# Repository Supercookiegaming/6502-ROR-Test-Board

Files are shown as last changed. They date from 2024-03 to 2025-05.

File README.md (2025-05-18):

# 6502-ROR-Test-Board

The 6502 ROR Test Board is a simple computer that tests if the ROR insruction is present on the 6502. I/O space is from 0x0000 to 0x7FFF. Rom space starts at 0x8000 and ends at 0xFFFF. The LED is tied to bit 7 and is set when the CPU R/W is low (writing). The data is then latched into the D-Latch and will be held until updated. The Yes ROR LED is turned on when the cpu writes to any memeory in the I/O space and bit 7 is high, all other bits do nothing. The No ROR LED is turned on whent he cpu writes to any memeory in the I/O space and bit 7 is low.
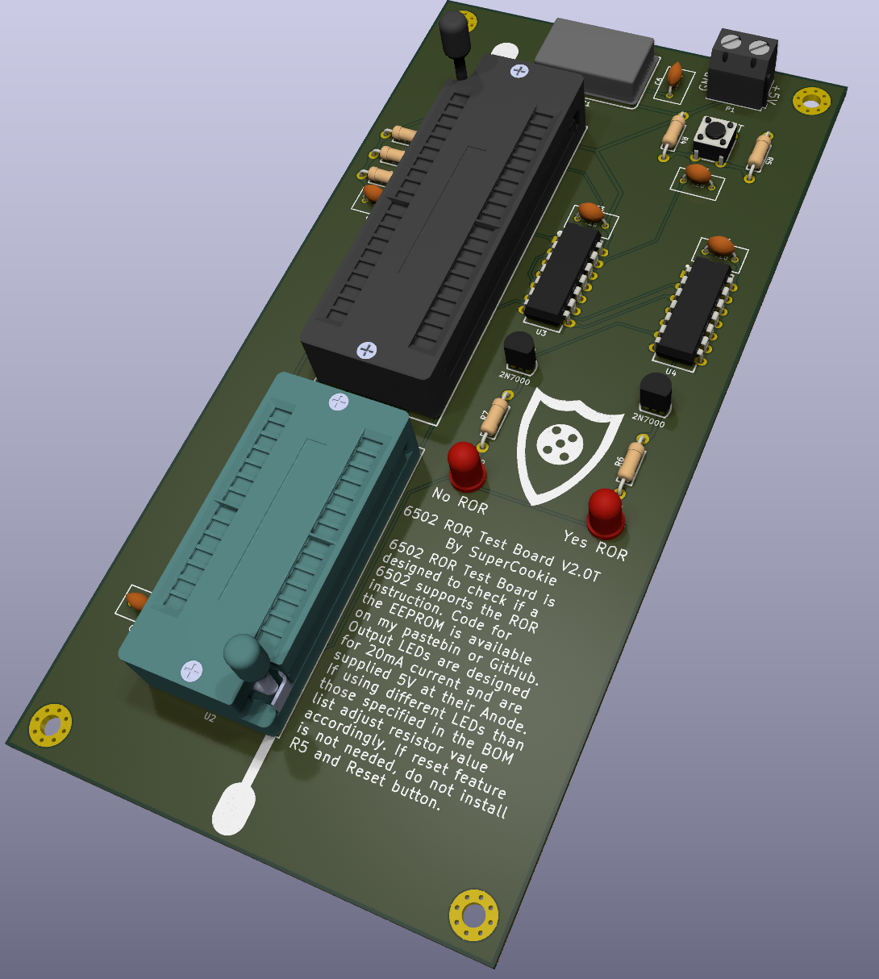
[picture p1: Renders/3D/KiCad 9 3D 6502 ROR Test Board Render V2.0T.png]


[logo]: https://github.com/Supercookiegaming/6502-ROR-Test-Board/blob/350ec1a620519f19180ad02e0bde4138ba3418b3/Renders/3D/KiCad%209%203D%206502%20ROR%20Test%20Board%20Render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
I used https://www.masswerk.at/6502/assembler.html to assemble the rom code and create a BIN file. When using https://www.masswerk.at/6502/# to emulate the board, use the code marked as "Emulator". When the ROR bug is enabled 0x0010 will be 00 and when it is disabled 0x0010 will be 80.

When Building your own board its best to use sockets.

V2.0S uses mostly SMD parts (mostly 0603). V2.0T only has through hole components. 

EasyEDA and KiCad 9 files are now available for both boards. 

The design is free for personally use only.

V2.0S and V2.0T both now support zif sockets for the 6502 and AT28C256, the imporved reset circuit design, ground M3 mounting points, and better silkscreen instructions and pinouts.

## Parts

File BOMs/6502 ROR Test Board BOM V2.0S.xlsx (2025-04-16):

Part | QTY | Link
2.2k Resistor | 4 | https://www.digikey.com/en/products/detail/walsin-technology-corporation/WR06X2201FTL/13238691
150 Resistor | 2 | https://www.digikey.com/en/products/detail/walsin-technology-corporation/WR06X151-JTL/13238810 | * It is strongly recommended to have zif sockets for the 6502 and AT28C256
0.1uF Capacitor | 6 | https://www.digikey.com/en/products/detail/meritek/MA1206XR104K101/20116994
2N7002 | 2 | https://www.mouser.com/ProductDetail/Nexperia/2N7002NXBKR?qs=%252B6g0mu59x7J2ddJstTJGkQ%3D%3D
SN74HCS74DR | 1 | https://www.digikey.com/en/products/detail/texas-instruments/SN74HCS74DR/12352265
SN74HCT14DR | 1 | https://www.digikey.com/en/products/detail/texas-instruments/SN74HCT14DR/562918
1Mhz Clock Generator | 1 | https://www.digikey.com/en/products/detail/analog-devices-inc-maxim-integrated/MAX7375AXR105-T/1520107
AT28C256 | 1 | https://www.mouser.com/ProductDetail/Microchip-Technology/AT28C256-15PU?qs=MAR%2F2X5XOp7eAU2%2FlNw9oA%3D%3D
6502 | 1
0603 LED | 2 | https://www.digikey.com/en/products/detail/harvatek-corporation/B19Y1USD-20C000113U1930/16602930
2 pin screw terminal | 1 | https://www.mouser.com/ProductDetail/845-30.702
Reset (optional)
smd button | 1 | https://www.lcsc.com/product-detail/Tactile-Switches_Korean-Hroparts-Elec-K2-1107ST-A4DW-06_C118141.html
150 Resistor | 1 | https://www.digikey.com/en/products/detail/walsin-technology-corporation/WR06X151-JTL/13238810
Normal Dip Sockets (optional*)
40 pin dip socket | 1 | https://www.jameco.com/z/40MTLP-Jameco-ValuePro-40-Pin-Machine-Tooled-Low-Profile-IC-Socket-0-6-Inch-Wide_41136.html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
28 pin dip socket | 1 | https://www.digikey.com/en/products/detail/mill-max-manufacturing-corp./110-44-628-41-001000/947065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
ZIF Sockets (optional*)
40 pin ZIF socket | 1 | https://www.adafruit.com/product/383#description
28 pin ZIF socket | 1 | https://www.ebay.com/itm/264998977768

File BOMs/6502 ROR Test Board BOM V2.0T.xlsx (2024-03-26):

Part | QTY | Link
2.2k Resistor | 4 | https://www.digikey.com/en/products/detail/stackpole-electronics-inc/CF14JT2K20/1830358?gad_source=1
150 Resistor | 2 | https://www.digikey.com/en/products/detail/stackpole-electronics-inc/CF18JT150R/1741590 | * It is strongly recommended to have zif sockets for the 6502 and AT28C256
0.1uF Capacitor | 6 | https://www.mouser.com/ProductDetail/Vishay-BC-Components/K104K10X7RF53H5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
2N7000 | 2 | https://www.digikey.com/en/products/detail/onsemi/2N7000/244278
SN74LS74AN | 1 | https://www.mouser.com/ProductDetail/Texas-Instruments/SN74LS74AN?qs=b0gIXGU74fP41yYZQO4%252BKQ%3D%3D
SN74HCT14N | 1 | https://www.mouser.com/ProductDetail/Texas-Instruments/SN74HCT14N?qs=d9gICRQKuCds9VLhv7zR%2Fg%3D%3D
1Mhz Clock Generator | 1 | https://www.mouser.com/ProductDetail/CTS-Electronic-Components/MXO45-3C-1M0000?qs=hbgUSdfWRJUFs0kP0zCadA%3D%3D
AT28C256 | 1 | https://www.mouser.com/ProductDetail/Microchip-Technology/AT28C256-15PU?qs=MAR%2F2X5XOp7eAU2%2FlNw9oA%3D%3D
6502 | 1
333-2SURD/S530-A3 LED | 2 | https://www.lcsc.com/product-detail/Light-Emitting-Diodes-LED_Everlight-Elec-333-2SURD-S530-A3_C87271.html
2 pin screw terminal | 1 | https://www.mouser.com/ProductDetail/845-30.702
Reset (optional)
6x6mm button | 1 | https://www.digikey.com/en/products/detail/cui-devices/TS02-66-60-BK-100-LCR-D/15634327?gad_source=1
150 Resistor | 1 | https://www.digikey.com/en/products/detail/stackpole-electronics-inc/CF18JT150R/1741590
Normal Dip Sockets (optional*)
40 pin dip socket | 1 | https://www.jameco.com/z/40MTLP-Jameco-ValuePro-40-Pin-Machine-Tooled-Low-Profile-IC-Socket-0-6-Inch-Wide_41136.html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
28 pin dip socket | 1 | https://www.digikey.com/en/products/detail/mill-max-manufacturing-corp./110-44-628-41-001000/947065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
14 pin dip socket | 2 | https://www.digikey.com/en/products/detail/on-shore-technology-inc./SA143040/3313523?gad_source=1
ZIF Sockets (optional*)
40 pin ZIF socket | 1 | https://www.adafruit.com/product/383#description
28 pin ZIF socket | 1 | https://www.ebay.com/itm/264998977768

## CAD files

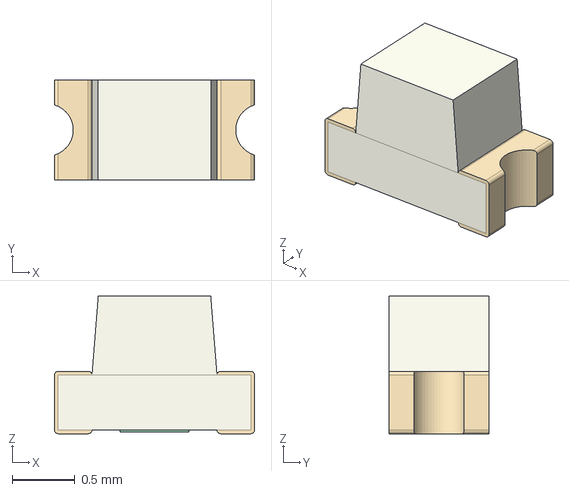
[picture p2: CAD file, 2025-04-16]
EDA Files/KiCad 9 6502 ROR Test Board V2.0S/LED_0603_1608Metric_Castellated.step
1.60 x 0.8 x 1.10 mm

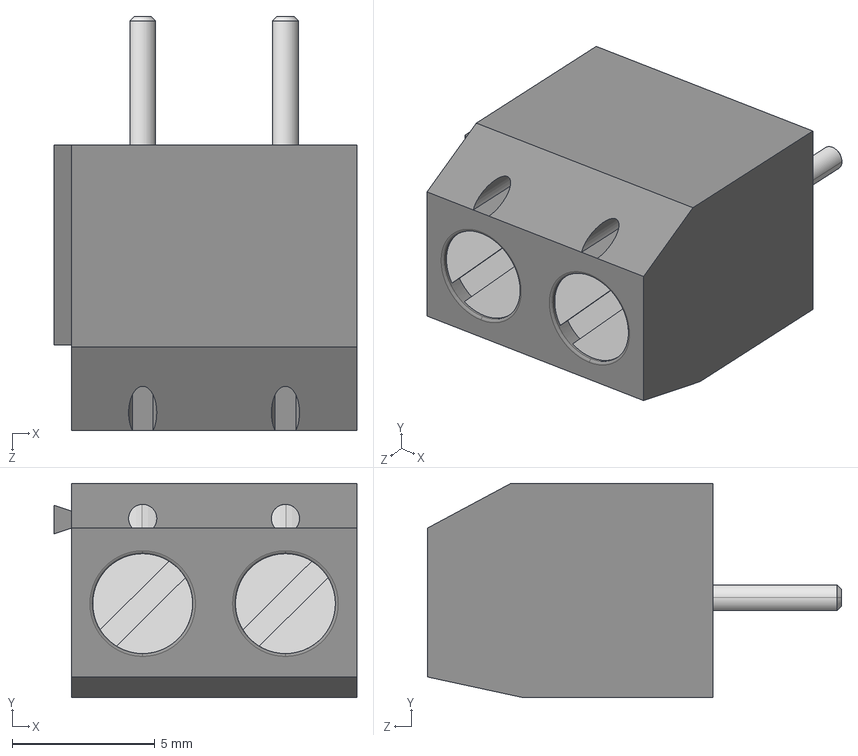
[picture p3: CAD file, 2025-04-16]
EDA Files/KiCad 9 6502 ROR Test Board V2.0T/30.702.stp
10.6 x 7.50 x 14.5 mm

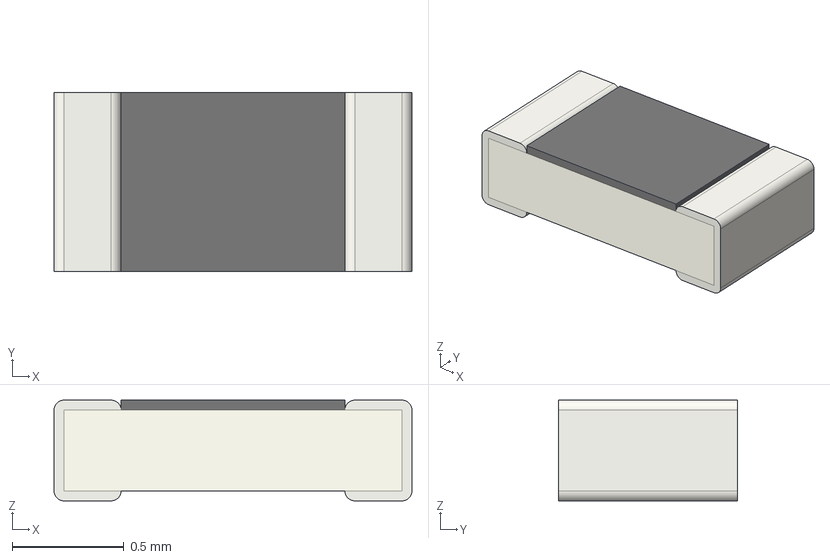
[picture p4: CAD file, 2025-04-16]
EDA Files/KiCad 9 6502 ROR Test Board V2.0S/R_0603_1608Metric.step
1.60 x 0.8 x 0.45 mm

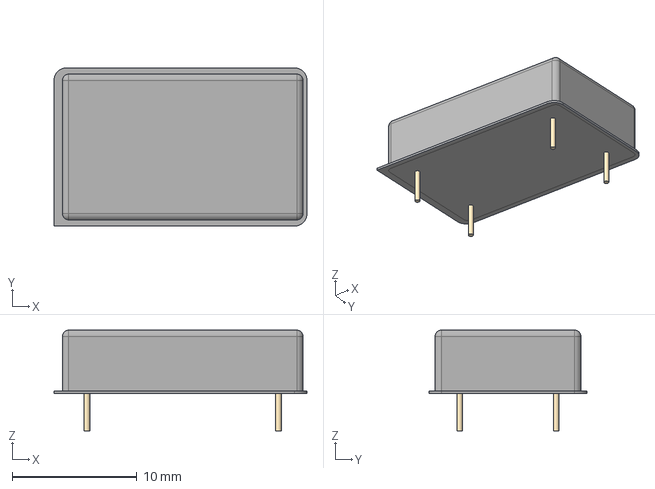
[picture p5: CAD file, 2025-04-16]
EDA Files/KiCad 9 6502 ROR Test Board V2.0T/Oscillator_DIP-14.step
20.3 x 12.7 x 8.08 mm

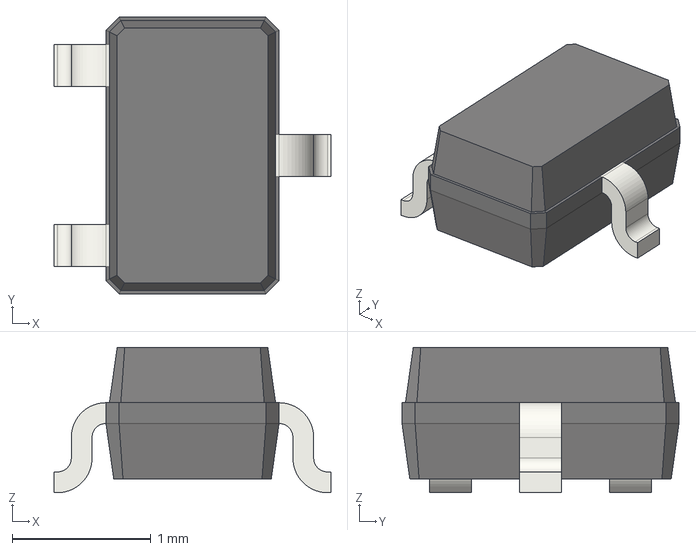
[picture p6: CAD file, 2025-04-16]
EDA Files/KiCad 9 6502 ROR Test Board V2.0S/SOT-323_SC-70.step
2.00 x 2.00 x 1.05 mm

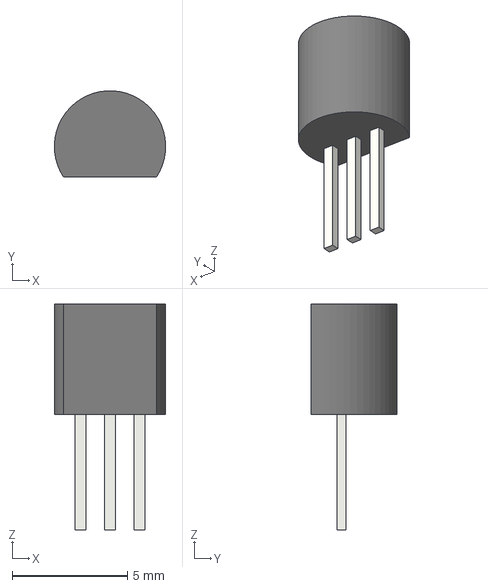
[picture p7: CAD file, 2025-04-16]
EDA Files/KiCad 9 6502 ROR Test Board V2.0T/TO-92_Inline.step
4.83 x 3.74 x 9.80 mm

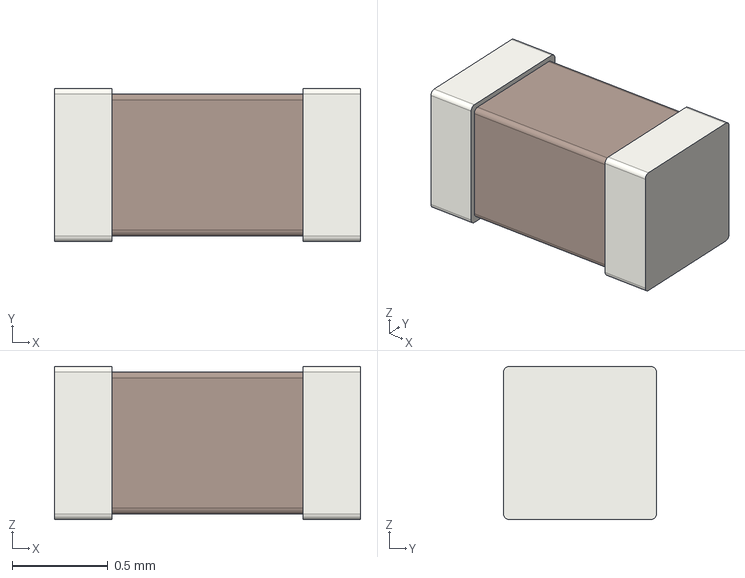
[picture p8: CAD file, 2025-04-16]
EDA Files/KiCad 9 6502 ROR Test Board V2.0S/C_0603_1608Metric.step
1.60 x 0.8 x 0.8 mm

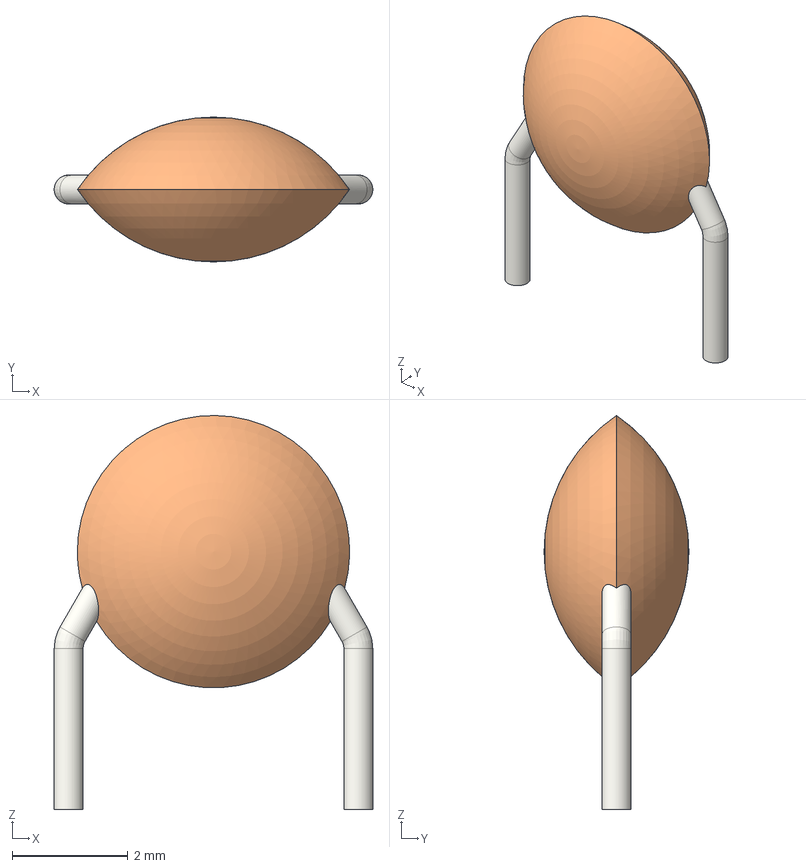
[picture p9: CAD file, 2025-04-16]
EDA Files/KiCad 9 6502 ROR Test Board V2.0T/C_Disc_D4.7mm_W2.5mm_P5.00mm.step
5.50 x 2.50 x 6.80 mm

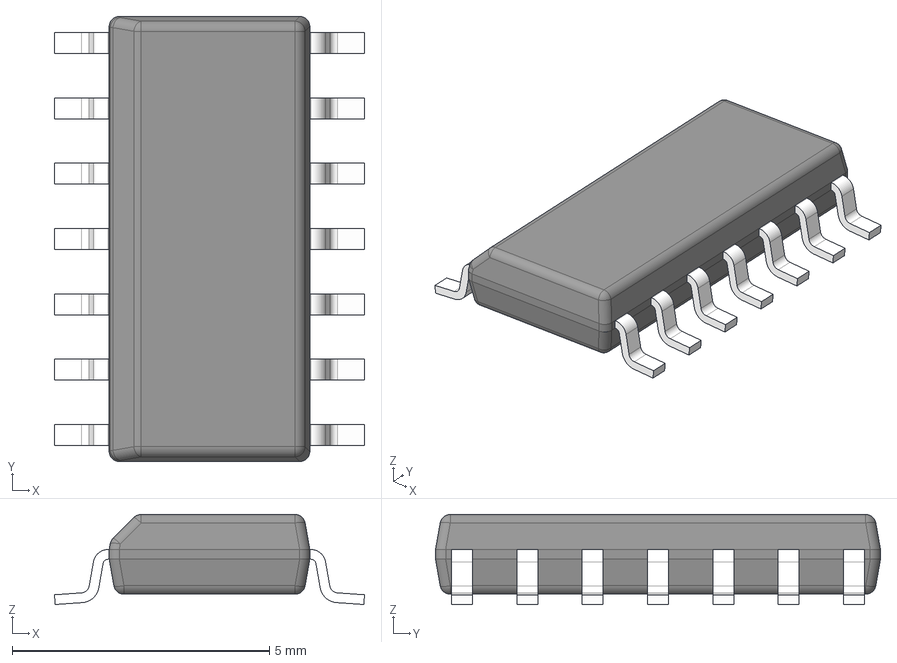
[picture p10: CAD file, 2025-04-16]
EDA Files/KiCad 9 6502 ROR Test Board V2.0S/SN74HCT14DR.stp
6.03 x 8.65 x 1.75 mm
BODY-SO
LEAD-SO x 14
PIN1-ID

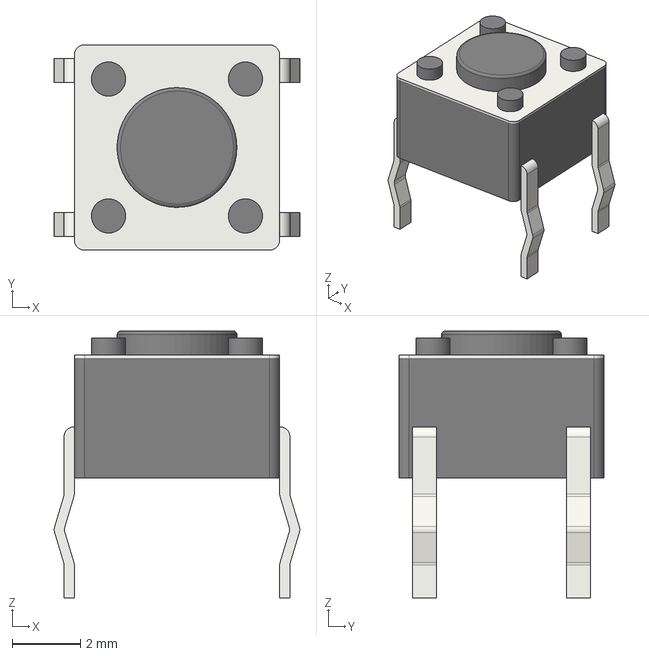
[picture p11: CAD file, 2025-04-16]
EDA Files/KiCad 9 6502 ROR Test Board V2.0T/SW_PUSH_6mm.step
7.17 x 6.00 x 7.80 mm

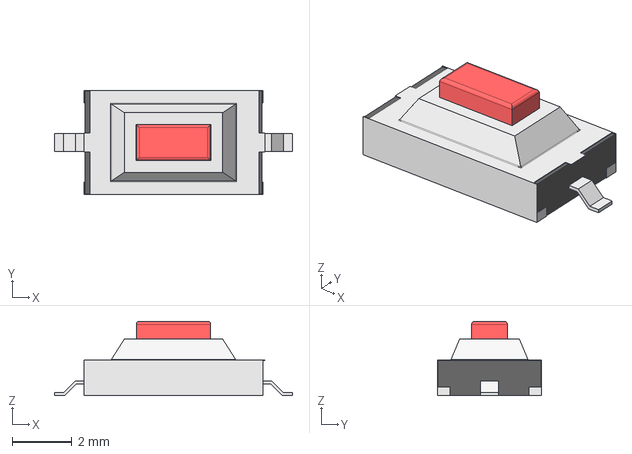
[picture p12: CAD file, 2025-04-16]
EDA Files/KiCad 9 6502 ROR Test Board V2.0S/SW_SPST_CK_RS282G05A3.step
8.00 x 3.50 x 2.50 mm

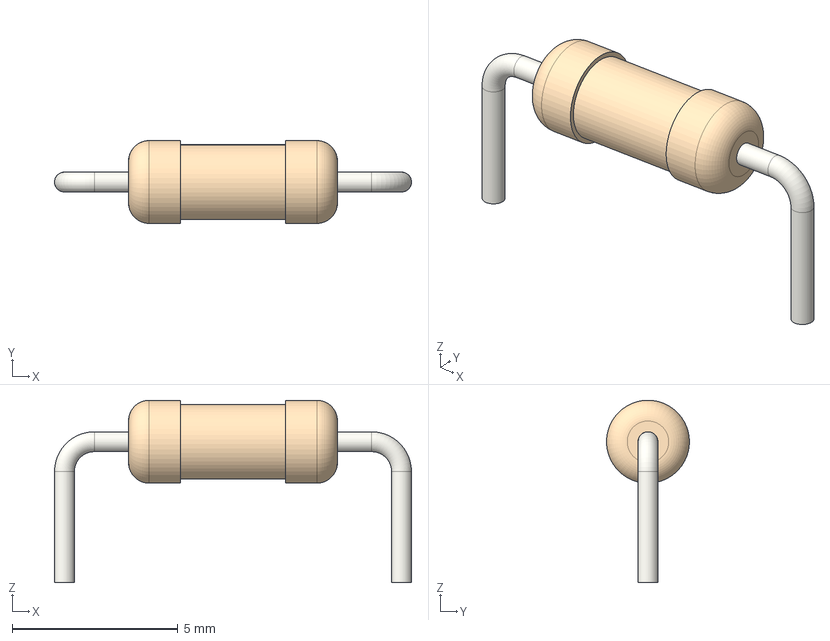
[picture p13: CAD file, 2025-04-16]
EDA Files/KiCad 9 6502 ROR Test Board V2.0T/R_Axial_DIN0207_L6.3mm_D2.5mm_P10.16mm_Horizontal.step
10.8 x 2.50 x 5.50 mm

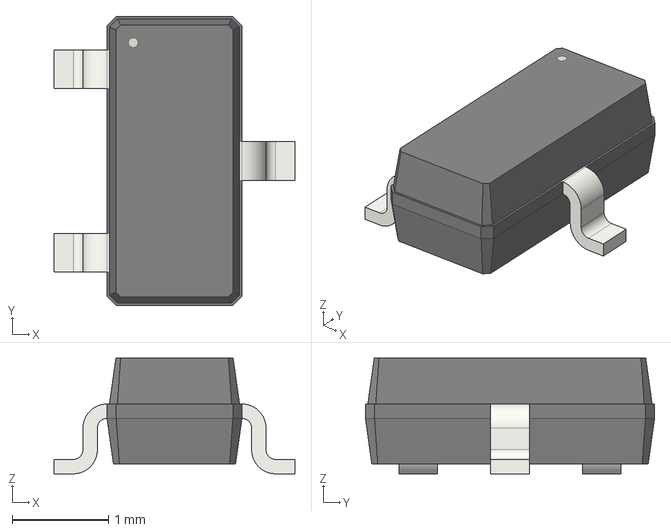
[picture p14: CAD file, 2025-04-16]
EDA Files/KiCad 9 6502 ROR Test Board V2.0S/SOT-23-3.step
2.50 x 3.00 x 1.20 mm

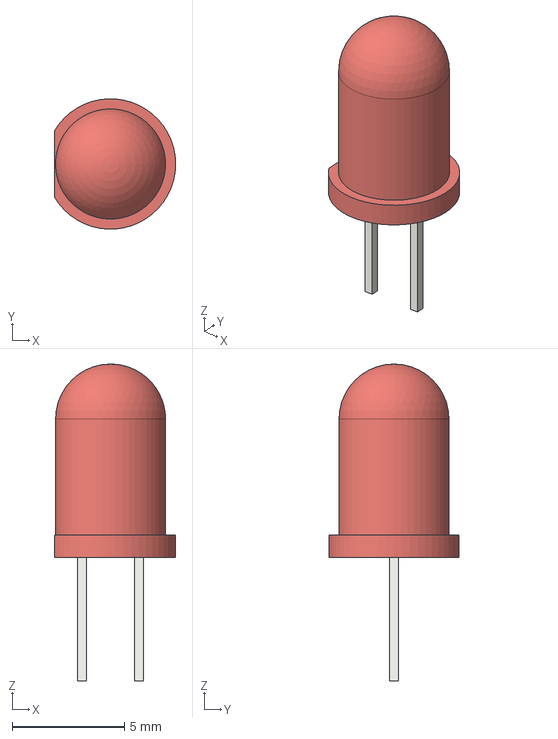
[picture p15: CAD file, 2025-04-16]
EDA Files/KiCad 9 6502 ROR Test Board V2.0T/LED_D5.0mm.step
5.40 x 5.79 x 14.1 mm

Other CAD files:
EDA Files/KiCad 9 6502 ROR Test Board V2.0T/DIP-14_W7.62mm.step
EDA Files/KiCad 9 6502 ROR Test Board V2.0S/228-1277-00-0602J.STEP
EDA Files/KiCad 9 6502 ROR Test Board V2.0T/240-1280-00-0602J.STEP
EDA Files/KiCad 9 6502 ROR Test Board V2.0S/240-1280-00-0602J.STEP
EDA Files/KiCad 9 6502 ROR Test Board V2.0T/228-1277-00-0602J.STEP

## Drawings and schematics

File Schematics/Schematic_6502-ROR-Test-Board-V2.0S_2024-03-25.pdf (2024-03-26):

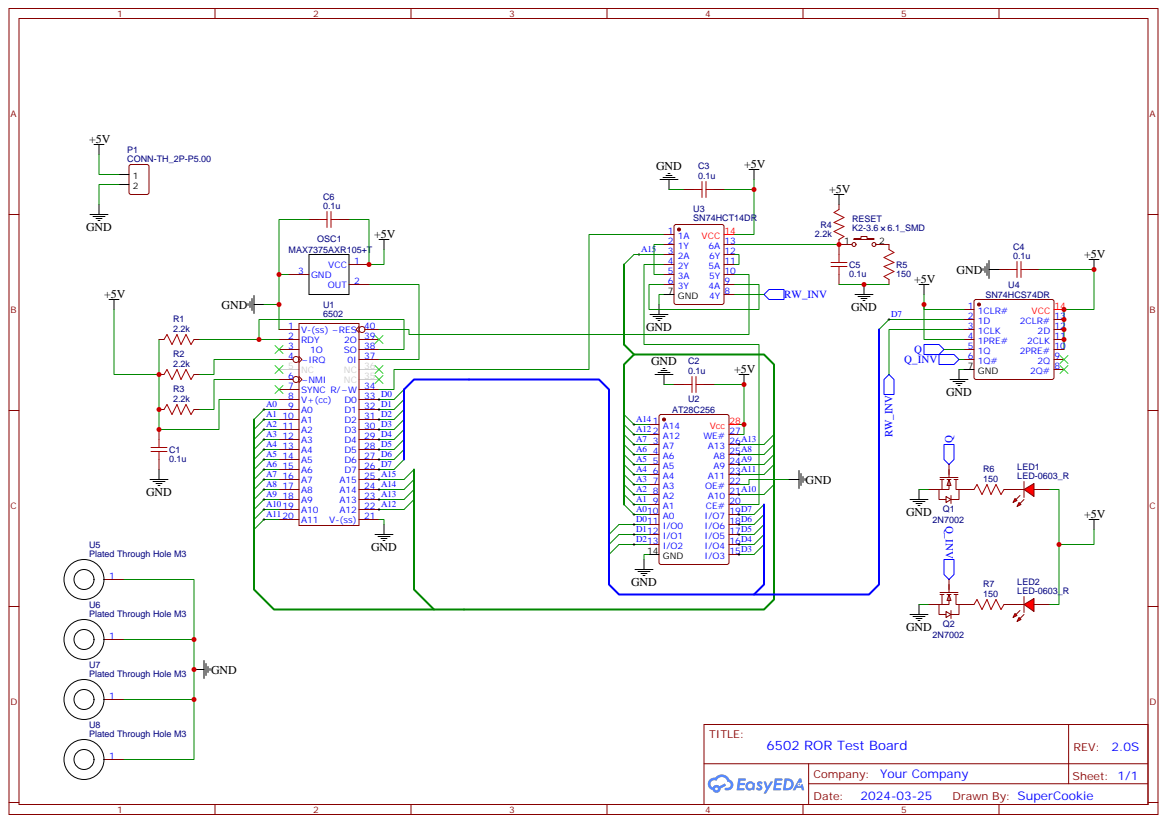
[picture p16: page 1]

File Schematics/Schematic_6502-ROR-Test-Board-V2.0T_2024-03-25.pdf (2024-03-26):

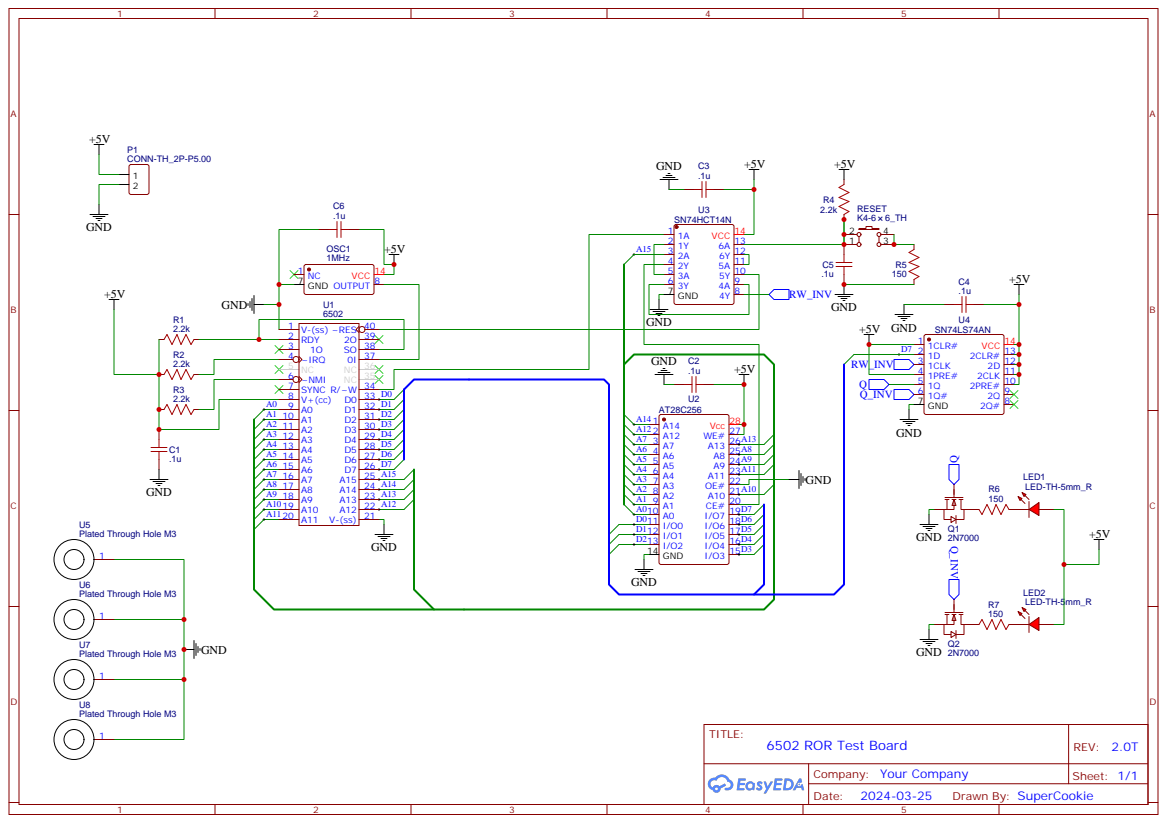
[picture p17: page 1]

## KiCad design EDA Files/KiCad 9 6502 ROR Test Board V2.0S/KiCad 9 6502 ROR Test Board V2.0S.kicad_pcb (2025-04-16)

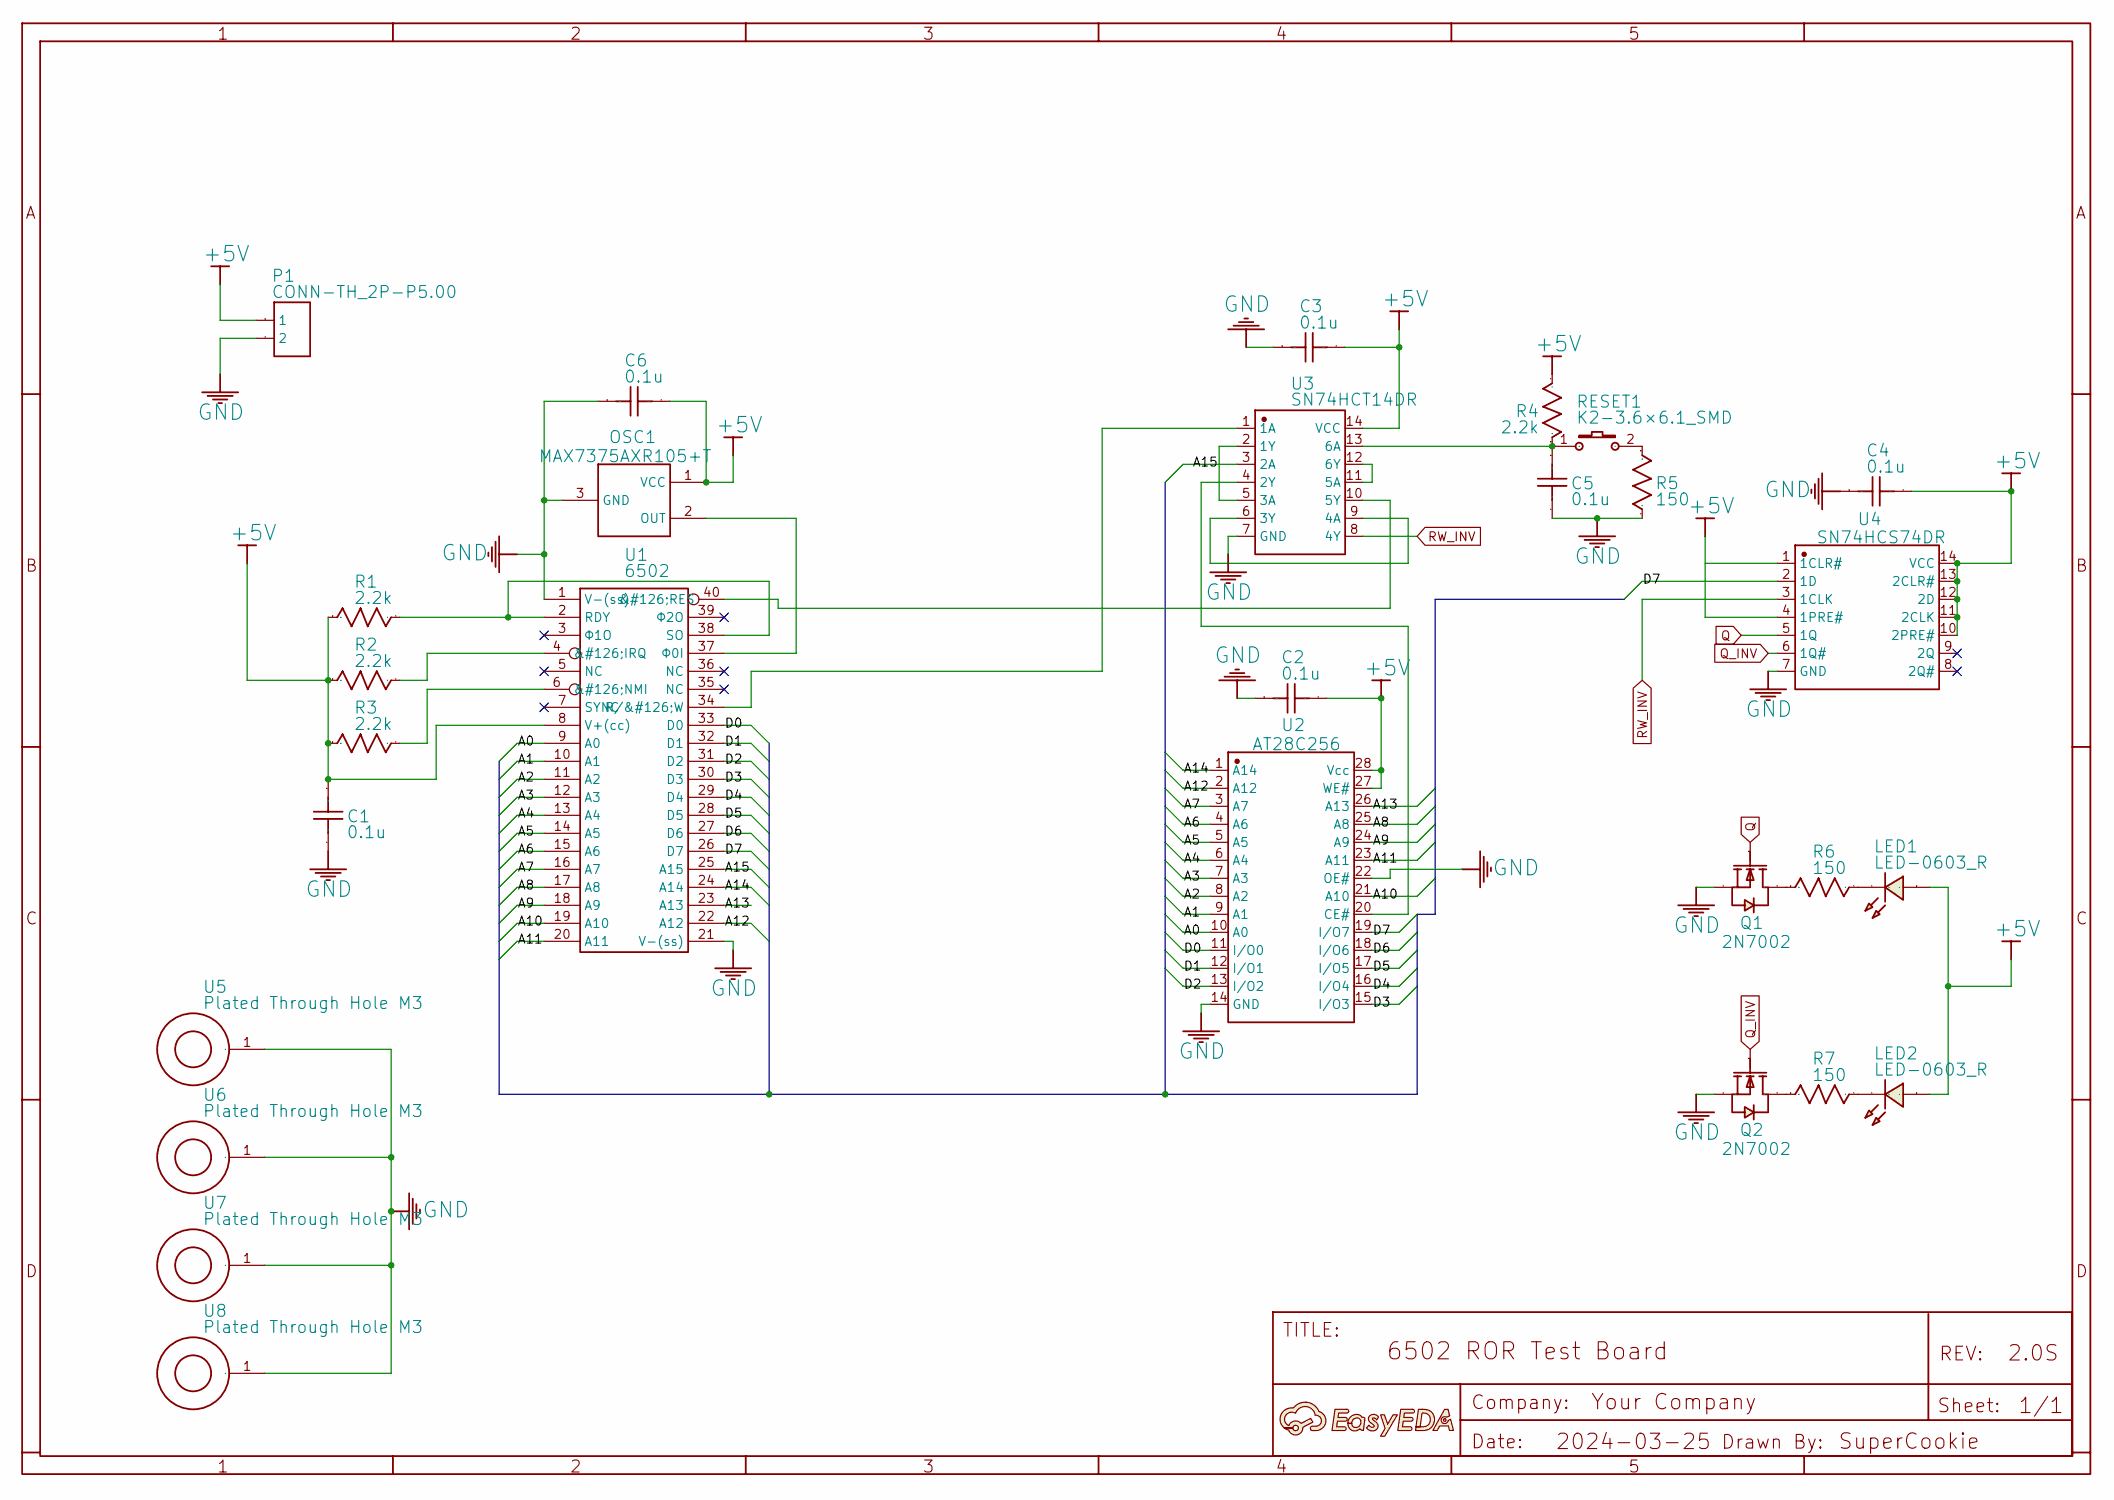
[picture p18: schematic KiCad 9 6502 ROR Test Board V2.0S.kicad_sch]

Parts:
A1: A; Manufacturer Part ?
C1, C2, C3, C4, C5, C6: 0.1u
LED1, LED2: LED-0603_R; Manufacturer Part 19-217/R6C-AL1M2VY/3T
OSC1: MAX7375AXR105+T; Manufacturer Part MAX7375AXR105+T
P1: CONN-TH_2P-P5.00
Q1, Q2: 2N7002; Manufacturer Part 2N7002,215
R1, R2, R3, R4: 2.2k
R5, R6, R7: 150
RESET1: K2-3.6×6.1_SMD; Manufacturer Part K2-1107ST-A4SW-06
U1: 6502
U2: AT28C256; Manufacturer Part AT28C256-15PU
U3: SN74HCT14DR; Manufacturer Part SN74HCT14DR
U4: SN74HCS74DR; Manufacturer Part SN74HCS74DR
U5, U6, U7, U8: Plated Through Hole M3

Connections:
+5V: C1.1, C2.2, C3.2, C4.2, C6.2, LED1.1, LED2.1, OSC1.1 (VCC), P1.1, R1.1, R2.1, R3.1, R4.2, U1.8 (V+(cc)), U2.27 (WE#), U2.28 (Vcc), U3.14 (VCC), U4.4 (1PRE#), U4.10 (2PRE#), U4.11 (2CLK), U4.12 (2D), U4.13 (2CLR#), U4.14 (VCC)
/A0: U1.9 (A0), U2.10 (A0)
/A1: U1.10 (A1), U2.9 (A1)
/A2: U1.11 (A2), U2.8 (A2)
/A3: U1.12 (A3), U2.7 (A3)
/A4: U1.13 (A4), U2.6 (A4)
/A5: U1.14 (A5), U2.5 (A5)
/A6: U1.15 (A6), U2.4 (A6)
/A7: U1.16 (A7), U2.3 (A7)
/A8: U1.17 (A8), U2.25 (A8)
/A9: U1.18 (A9), U2.24 (A9)
/A10: U1.19 (A10), U2.21 (A10)
/A11: U1.20 (A11), U2.23 (A11)
/A12: U1.22 (A12), U2.2 (A12)
/A13: U1.23 (A13), U2.26 (A13)
/A14: U1.24 (A14), U2.1 (A14)
/A15: U1.25 (A15), U3.3 (2A)
/D0: U1.33 (D0), U2.11 (I/O0)
/D1: U1.32 (D1), U2.12 (I/O1)
/D2: U1.31 (D2), U2.13 (I/O2)
/D3: U1.30 (D3), U2.15 (I/O3)
/D4: U1.29 (D4), U2.16 (I/O4)
/D5: U1.28 (D5), U2.17 (I/O5)
/D6: U1.27 (D6), U2.18 (I/O6)
/D7: U1.26 (D7), U2.19 (I/O7), U4.2 (1D)
GND: C1.2, C2.1, C3.1, C4.1, C5.2, C6.1, OSC1.3 (GND), P1.2, Q1.2 (S), Q2.2 (S), R5.2, U1.1 (V-(ss)), U1.21 (V-(ss)), U2.14 (GND), U2.22 (OE#), U3.7 (GND), U4.7 (GND), U5.1, U6.1, U7.1, U8.1
unnamed: LED1.2, R6.2
unnamed: LED2.2, R7.2
unnamed: OSC1.2 (OUT), U1.37 (Φ0I)
unnamed: Q1.3 (D), R6.1
unnamed: Q2.3 (D), R7.1
unnamed: R5.1, RESET1.2
unnamed: R2.2, U1.4 (&#126;IRQ)
unnamed: R3.2, U1.6 (&#126;NMI)
unnamed: U1.40 (&#126;RES), U3.10 (5Y)
unnamed: R1.2, U1.2 (RDY), U1.38 (SO)
unnamed: U1.34 (R/&#126;W), U3.1 (1A)
unnamed: U2.20 (CE#), U3.4 (2Y)
unnamed: U3.2 (1Y), U3.5 (3A)
unnamed: U3.6 (3Y), U3.9 (4A)
unnamed: U3.11 (5A), U3.12 (6Y)
Q: Q1.1 (G), U4.5 (1Q)
Q_INV: Q2.1 (G), U4.6 (1Q#)
R4_1: C5.1, R4.1, RESET1.1, U3.13 (6A); also elsewhere on the board
RW_INV: U3.8 (4Y), U4.3 (1CLK)

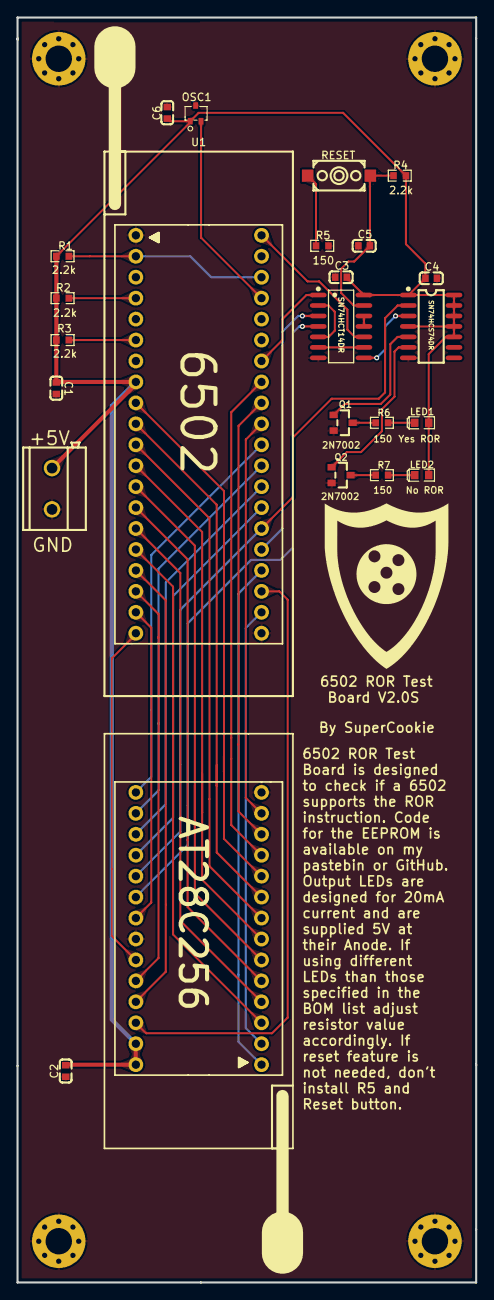
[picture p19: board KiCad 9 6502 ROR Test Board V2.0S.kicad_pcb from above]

Board: 2 copper layers, 55.6 x 153.4 mm, 28 parts (0 on the bottom side), 44 nets.

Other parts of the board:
RESET: K2-3.6×6.1_SMD; KEY-SMD_2P-L6.2-W3.6-LS8.0

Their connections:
R4_1: RESET.1; also elsewhere on the board

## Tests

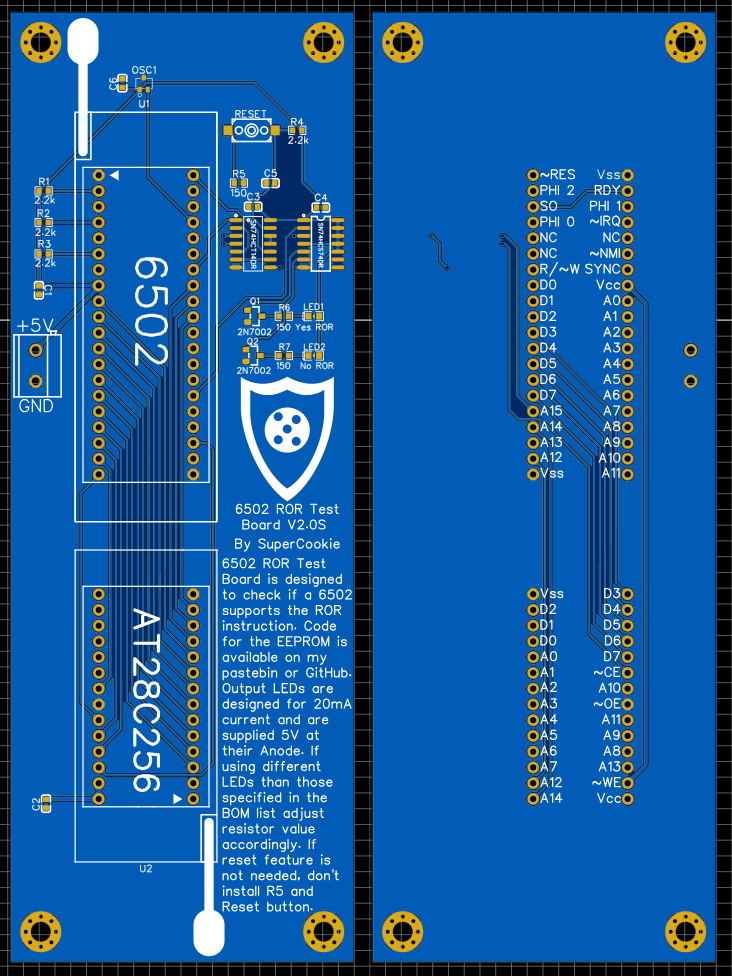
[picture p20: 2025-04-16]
Renders/2D/EasyEDA 6502 ROR Test Board Render V2.0S.png

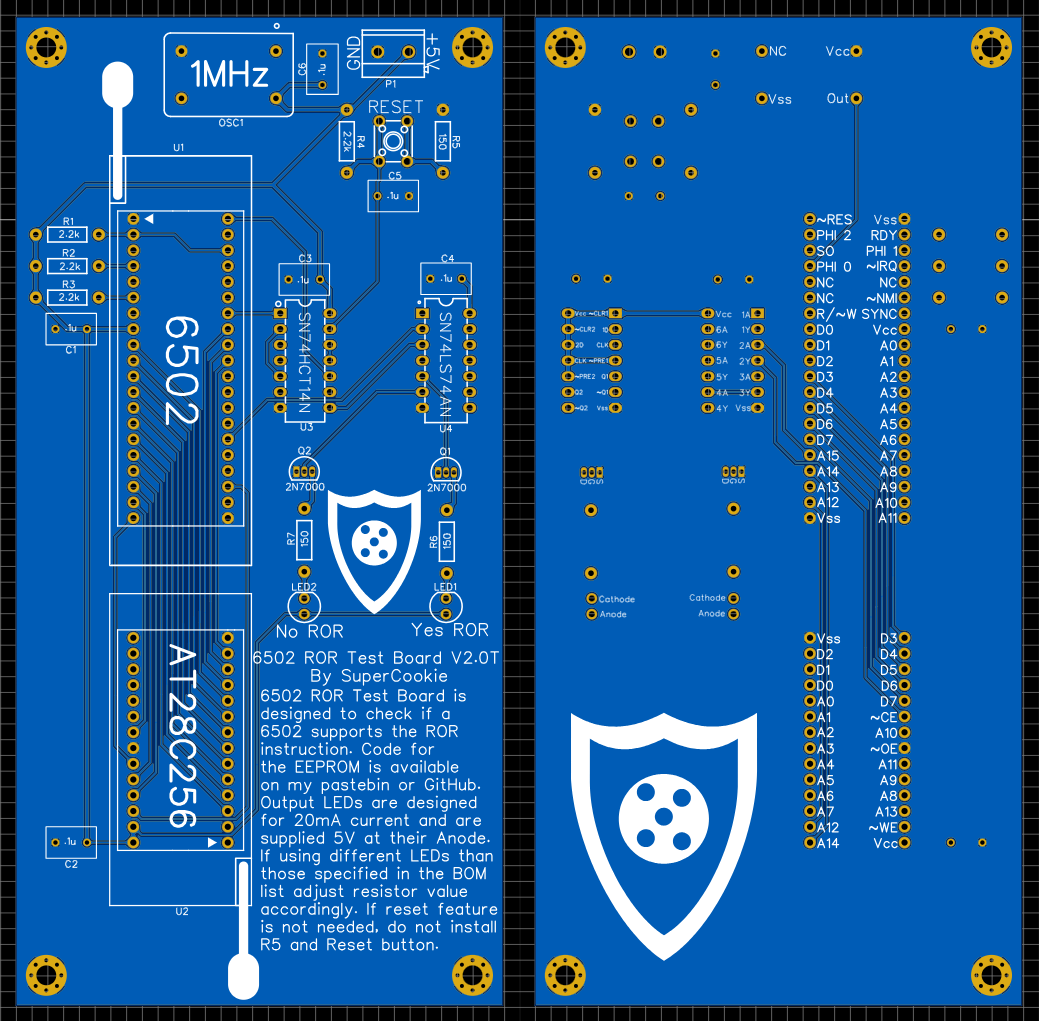
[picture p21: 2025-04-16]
Renders/2D/EasyEDA 6502 ROR Test Board Render V2.0T.png

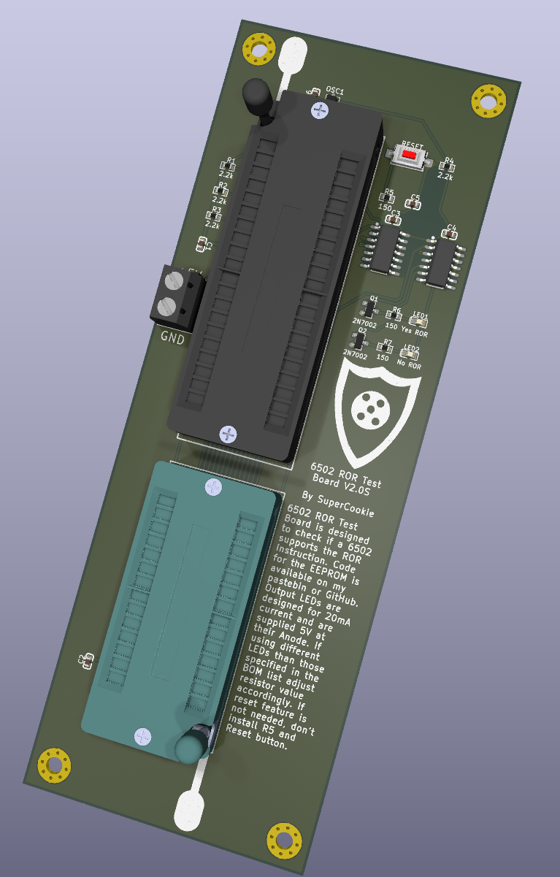
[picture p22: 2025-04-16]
Renders/3D/KiCad 9 3D 6502 ROR Test Board Render V2.0S.png

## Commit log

2023-12-22 Add files via upload
    V1.1 only uses through hole components. replaced the SN74LVC1G373DCKR with a SN74LS00N.
    [6502 ROR Test Board BOM V1.1.xlsx]
2023-12-22 Update 6502 ROR Test Board ROM Source Code.txt
2023-12-22 Rename 6502 ROR Test Board BOM.xlsx to 6502 ROR Test Board BOM V1.0.xlsx
    [6502 ROR Test Board BOM V1.0.xlsx]
2023-12-22 Rename 6502 ROR Test Board BOM V1.0.xlsx to 6502 ROR Test Board BOM V1.xlsx
    [6502 ROR Test Board BOM V1.xlsx]
2023-12-22 Add files via upload
    changed 2N7002 to correct 2N7000. added sockets for 555 and 74LS00
    [6502 ROR Test Board BOM V1.1.xlsx]
2023-12-24 Updated V1.1 to support optional ZIF sockets
    [6502 ROR Test Board BOM V1.1.xlsx]
2023-12-24 Cost reduced V1.1
    changed reset circuit to RC type. added push button reset option. reduced cost by remove 555 and changing 74LS00 to a hex shmitt trigger inverter (SN74HCT14N) and a D-Type Latch and Flip-Flop (SN74LS74AN). also reduced types of components needed to 1 type of capacitor and 2 types of resistor. Added better skillscreen instructions. Also added pinouts for all ICs on the back of the board skillscreen.
    [6502 ROR Test Board BOM V1.1.xlsx]
2023-12-26 Updated Designes
    Moved V1 to all smd parts (where possible) to reduce size and cost. Updated V1 to have the cheaper/more capable reset circuit of V1.1. Updated silkscreen instructions on both boards. added capacitor for crystal oscillators. updated BOM lists for both versions.
    [6502 ROR Test Board BOM V1.1.xlsx, 6502 ROR Test Board BOM V1.xlsx]
2023-12-26 Rename EasyEDA ROR Test Board V1.1.zip to EasyEDA 6502 ROR Test Board V1.1.zip
2023-12-26 added ground m3 mounting holes
2023-12-26 fixed incorrect silkscreen marking
2024-03-26 Updated design
    updated design to add delay to d latch clk input to match requirements of datasheet.
    updated smd design to be easier to solder
    changed naming scheme to so it is easier to differentiate between he SMD and Through hole versions.
    updated BOM to reflect changes
    [6502 ROR Test Board BOM V2.0S.xlsx, 6502 ROR Test Board BOM V2.0T.xlsx]
2025-04-16 Added KiCad 9 V2.0S Version
    converted easyeda V2.0S files to KiCad 9 files
    [228-1277-00-0602J.STEP, 240-1280-00-0602J.STEP, KiCad 9 6502 ROR Test Board V2.0S.kicad_pcb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]
2025-04-16 Added KiCad 9 V2.0T Version
    converted easyeda V2.0T files to KiCad 9 files
    renamed renders to EasyEDA Renders
    [228-1277-00-0602J.STEP, 240-1280-00-0602J.STEP, KiCad 9 6502 ROR Test Board V2.0T.kicad_pcb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]
2025-04-16 Added 3D Renders
    Added basic 3D Renders
    [KiCad 9 6502 ROR Test Board V2.0S.kicad_pcb, KiCad 9 6502 ROR Test Board V2.0T.kicad_pcb]
2025-04-16 Adding 3D models for KiCad V2.0T
    [C_Disc_D4.7mm_W2.5mm_P5.00mm.step, KiCad 9 6502 ROR Test Board V2.0T.kicad_pcb, LED_D5.0mm.step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]
2025-04-16 added 3D models to KiCad
    Added 3D Models of components to both KiCad Boards
    Fixed footprint of screw terminal to match with 30.702 on both easyeda and kicad files
    re-rendered 2D view from EasyEDA and added 3D view rendering from KiCad
    Renders in separate folder
    Exported new gerbers from both EasyEDA and KiCad with updated footprint
    Exported 3D model of both boards from KiCad and added to folder.
    Updated link to smd LED to active part.
    [30.702.stp, 6502 ROR Test Board BOM V2.0S.xlsx, C_0603_1608Metric.step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]
2025-04-16 KiCad backup update
2025-04-16 Moved Gerbers into New Folder
    moved gerbers into their own folder
2025-04-16 Organized file structure
    [228-1277-00-0602J.STEP, 240-1280-00-0602J.STEP, 30.702.stp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]
2025-05-18 Update README.md
    Fixed image of board in readme
2025-06-13 Updated file structure
    -deleted backup files for kicad
    -moved gerber files into gerber subfolder
    [KiCad 9 6502 ROR Test Board V2-BoardOutLine.gbr, KiCad 9 6502 ROR Test Board V2-BottomLayer.gbr, KiCad 9 6502 ROR Test Board V2-BottomPasteMaskLayer.gbr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]

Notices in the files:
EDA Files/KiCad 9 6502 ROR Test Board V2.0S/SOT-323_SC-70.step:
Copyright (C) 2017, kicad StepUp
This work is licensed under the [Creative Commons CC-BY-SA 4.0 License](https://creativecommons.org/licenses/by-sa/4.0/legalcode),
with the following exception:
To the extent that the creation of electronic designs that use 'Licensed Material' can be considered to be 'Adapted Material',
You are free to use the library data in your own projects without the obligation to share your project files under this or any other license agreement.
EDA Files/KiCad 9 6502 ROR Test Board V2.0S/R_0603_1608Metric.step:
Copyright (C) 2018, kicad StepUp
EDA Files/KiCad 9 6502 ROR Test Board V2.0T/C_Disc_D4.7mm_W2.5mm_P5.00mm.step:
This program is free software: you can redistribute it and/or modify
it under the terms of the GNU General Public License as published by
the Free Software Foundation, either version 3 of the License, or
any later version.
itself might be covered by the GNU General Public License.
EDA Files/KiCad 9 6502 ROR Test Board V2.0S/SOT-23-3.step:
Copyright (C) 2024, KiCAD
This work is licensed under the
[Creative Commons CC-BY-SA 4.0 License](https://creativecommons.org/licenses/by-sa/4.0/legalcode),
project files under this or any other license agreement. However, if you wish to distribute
